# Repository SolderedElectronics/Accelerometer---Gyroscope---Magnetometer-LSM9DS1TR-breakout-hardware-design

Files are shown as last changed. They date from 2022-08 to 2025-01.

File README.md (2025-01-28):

# Accelerometer & Gyroscope & Magnetometer LSM9DS1TR 9-DOF breakout Hardware Design

## About the Product

| Accelerometer & Gyroscope & Magnetometer LSM9DS1TR 9-DOF breakout Image |
| :----------------------------------------------------------: |
| [Buy Accelerometer & Gyroscope & Magnetometer LSM9DS1TR 9-DOF breakout](https://www.solde.red/333069) |

Discover the magic of motion tracking with our all-in-one Accelerometer, Gyroscope & Magnetometer LSM9DS1TR Breakout! This mini but mighty module bundles together a 3D accelerometer, a 3D gyroscope, and a 3D magnetometer. It lets you monitor not only linear and rotational movements but also the magnetic field surrounding your projects. Despite its pocket-size, it offers high-accuracy measurements — ±16 g for the accelerometer, ±2000 dps for the gyroscope, and ±16 Gauss for the magnetometer.

It has an embedded temperature sensor, FIFO buffer for data management, and interrupt features to signal your microcontroller when data is ready or when a certain event occurs. Plus, with I2C interface, it can easily connect with a variety of microcontrollers.

Our LSM9DS1TR breakout merges high-end capabilities with a user-friendly approach. It operates within a supply voltage range of 2.4V to 3.6V, making it compatible with both 3.3V and 5V systems. Its low-power and power-down modes optimize performance without draining too much energy.

This breakout board comes with 2 easyC connectors which will simplify connection with microcontrollers. By using the easyC module connection system, forget about incorrectly connected or, in the worst case, damaged modules.

---

## Repository Contents

This repository contains all design files for Accelerometer & Gyroscope & Magnetometer LSM9DS1TR 9-DOF breakout, organized as follows:

- **`CAD` folder**: Contains KiCAD design files, including:
  - Schematics
  - PCB layout
  - Panel PCB layout
  - Source 3D files in Fusion360, if any
  - All files are sorted by version with a detailed change log.
- **`OUTPUTS` folder**: Includes all production-ready files, such as:
  - Bill of Materials (BOM) and interactive BOM (iBOM)
  - PDF versions of schematics
  - 3D `.step` file of the board
  - 3D-printable models
  - Gerber files for PCB manufacturing
  - Image of the pinout of the board
  - Product image
  - Compliance, legal and generic sales documents

Refer to the `Change Log` in the CAD folder for details about updates between versions.

---

## Learn More About the Product

Beyond the repository, explore the following resources:

### Soldered Verify

Soldered Verify Logo

The **Soldered Verify** system ensures every board you purchase from Soldered is fully functional. It also provides access to exclusive test data for your product. To get started, find the unique Soldered Verify ID on your product's packaging and enter the ID on the [Soldered Verify page](https://soldered.com/verify/) to access test results and additional product details.

### Soldered Community

soldered-verify-logo

Soldered Community is your go-to place for technical support. Our engineers track and answer all questions posted there, and it’s a great space for the maker community. Get answers to your questions and solutions for your challenges at [Soldered Community](https://soldered.com/community).

### solde.red

solde.red is an ultimate URL shortener and information hub. Access it by typing solde.red/ followed by your product SKU, e.g., [solde.red/333000](https://solde.red/333000), to find getting-started guides, datasheets, open-source hardware and software files, certifications, images, pinouts, and more. Read more about the shortener [here](https://solde.red/info/).

---

## Contributing

Contributions are welcome! Here’s how you can get involved:

- Submit pull requests to enhance the design or fix issues.
- Report bugs or problems by opening an issue.

We encourage community collaboration to make this product even better.

---

## About Soldered

soldered-logo

[Soldered for Makers](https://soldered.com) specializes in designing and manufacturing electronic products tailored for enthusiasts, ranging from hobbyists to professionals. Our portfolio includes electronic boards, sensors, and actuators that are widely utilized in fields such as microelectronics, mechatronics, robotics, programming, and IoT. Every product we offer is designed in-house and built upon open-source hardware and software platforms. Proudly certified and manufactured within the European Union, our catalog likely includes the product you need for your project.

We complement these products with comprehensive tutorials and manuals, product descriptions, schematics, programming codes, and project examples. Our round-the-clock [customer and technical support](https://soldered.com/community) is available for all our products, irrespective of the sales channel. Soldered’s success and services reflect our maker community’s unwavering [trust](https://www.trustpilot.com/review/soldered.com), for which we are deeply grateful. Join our community and create using Soldered products.

---

## License

All Soldered open-source hardware (OSH) is under The TAPR Open Hardware License. Read more in the LICENSE file located in this repository.

**Disclaimer:**

No warranty - all designs in this repository are distributed in the hope that they will be useful, but without any warranty. They are provided "AS IS", therefore without warranty of any kind, either expressed or implied. The entire quality and performance of what you do with the contents of this repository are your responsibility. In no event Soldered Electronics will be liable for your damages, or losses, including any general, special, incidental, or consequential damage arising out of the use or inability to use the contents of this repository. 

---

## Have fun!

Thank you for your support from your fellow makers at Soldered Electronics.

Happy Making!

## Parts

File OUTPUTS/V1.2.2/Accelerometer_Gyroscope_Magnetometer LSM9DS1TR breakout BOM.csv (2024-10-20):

Id | Designator | Package | Quantity | Designation | Supplier and ref
1 | R6,R4,R8,R2,R1,R7,R5,R3 | 0603R | 8 | 10k
2 | C6,C7 | 0603C | 2 | 2u2
3 | K2,K4 | easyC-connector | 2 | easyC-SMD
4 | JP6 | SMD-JUMPER-CONNECTED_TRACE_SLODERMASK | 1 | SMD-JUMPER-CONNECTED_TRACE_SLODERMASK
5 | C3 | 1206C | 1 | 10u
6 | C5,C2,C1 | 0603C | 3 | 100n
7 | REF** | Symbol-Front-Orientation2 | 1 | Symbol-Front-Orientation2
8 | JP5,JP1,JP2,JP3 | SMD_JUMPER_3_PAD_TRACE | 4 | SMD_JUMPER_3_PAD_TRACE
9 | U1 | SOT-363 | 1 | NMOS-DUAL
10 | C4 | 0603C | 1 | 10n
11 | U3 | SOT-23-5 | 1 | SE5218
12 | U2 | LSM9DS1TR | 1 | LSM9DS1TR
13 | H1,H2 | HOLE_3.2mm | 2 | HOLE_3.2mm
14 | JP4 | SMD_JUMPER | 1 | SMD_JUMPER
15 | K3 | HEADER_MALE_4X1 | 1 | HEADER_MALE_4X1
16 | K1 | HEADER_MALE_9X1 | 1 | HEADER_MALE_9X1

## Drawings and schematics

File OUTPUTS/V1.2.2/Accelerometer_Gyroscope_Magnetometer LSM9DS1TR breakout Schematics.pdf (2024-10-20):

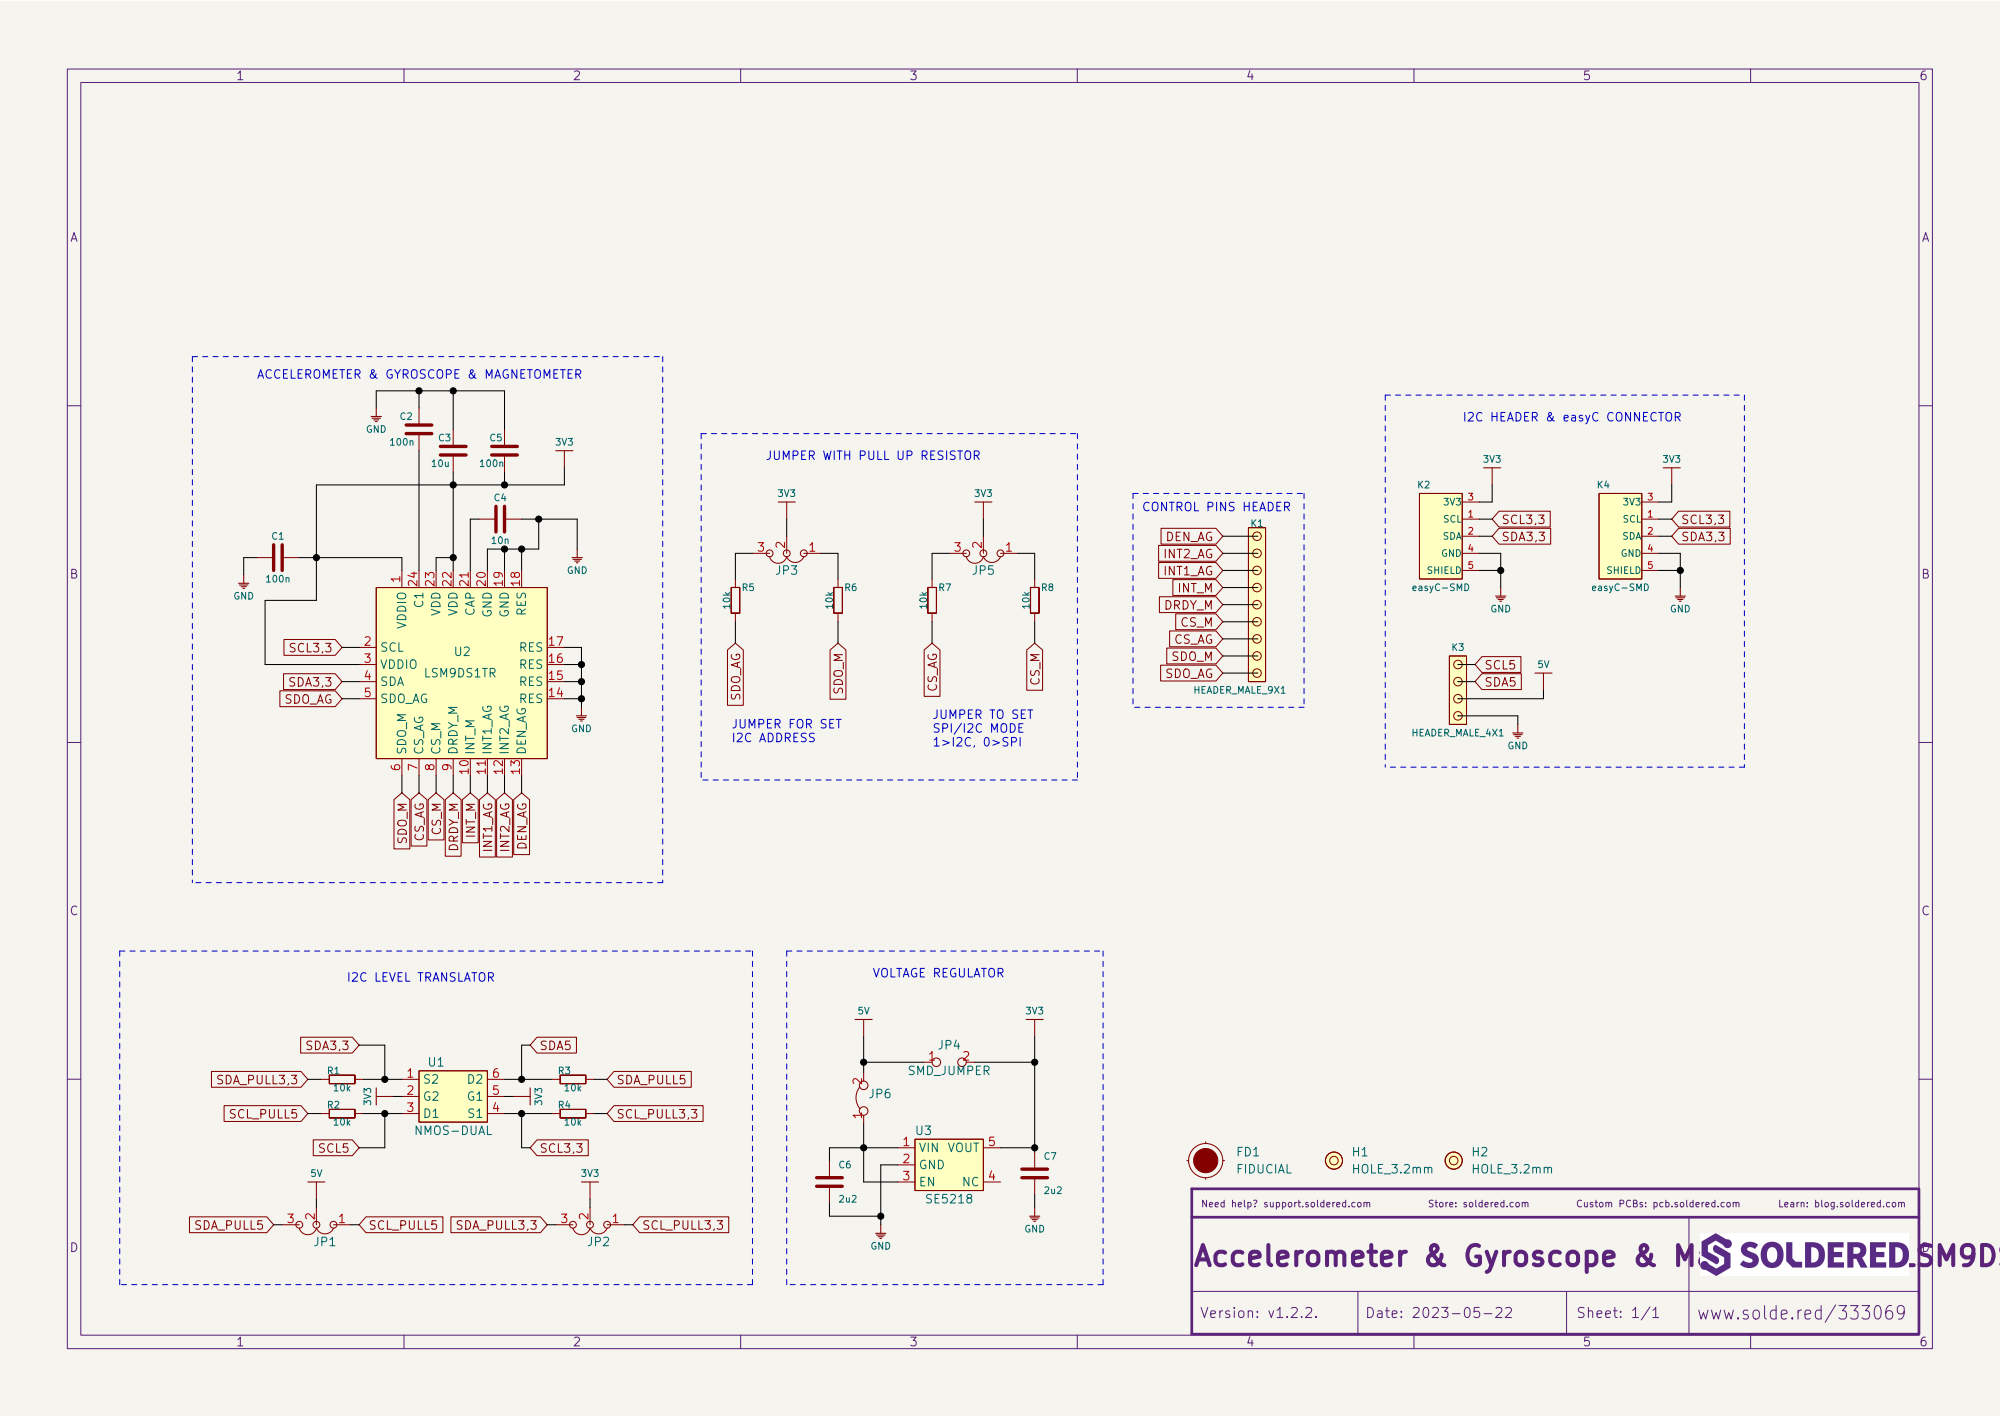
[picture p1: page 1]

JUMPER WITH PULL UP RESISTOR

1 INT_M 10 INT1_AG 11 INT2_AG 12 DEN_AG 13 RES 14 RES 15 RES 16 RES 17 RES 18 GND 19 SCL 2 GND 20 CAP 21 VDD 22 VDD 23 C1 24 VDDIO 3 SDA 4 SDO_AG 5 SDO_M

JUMPER TO SET SPI/I2C MODE

Learn: blog.soldered.com

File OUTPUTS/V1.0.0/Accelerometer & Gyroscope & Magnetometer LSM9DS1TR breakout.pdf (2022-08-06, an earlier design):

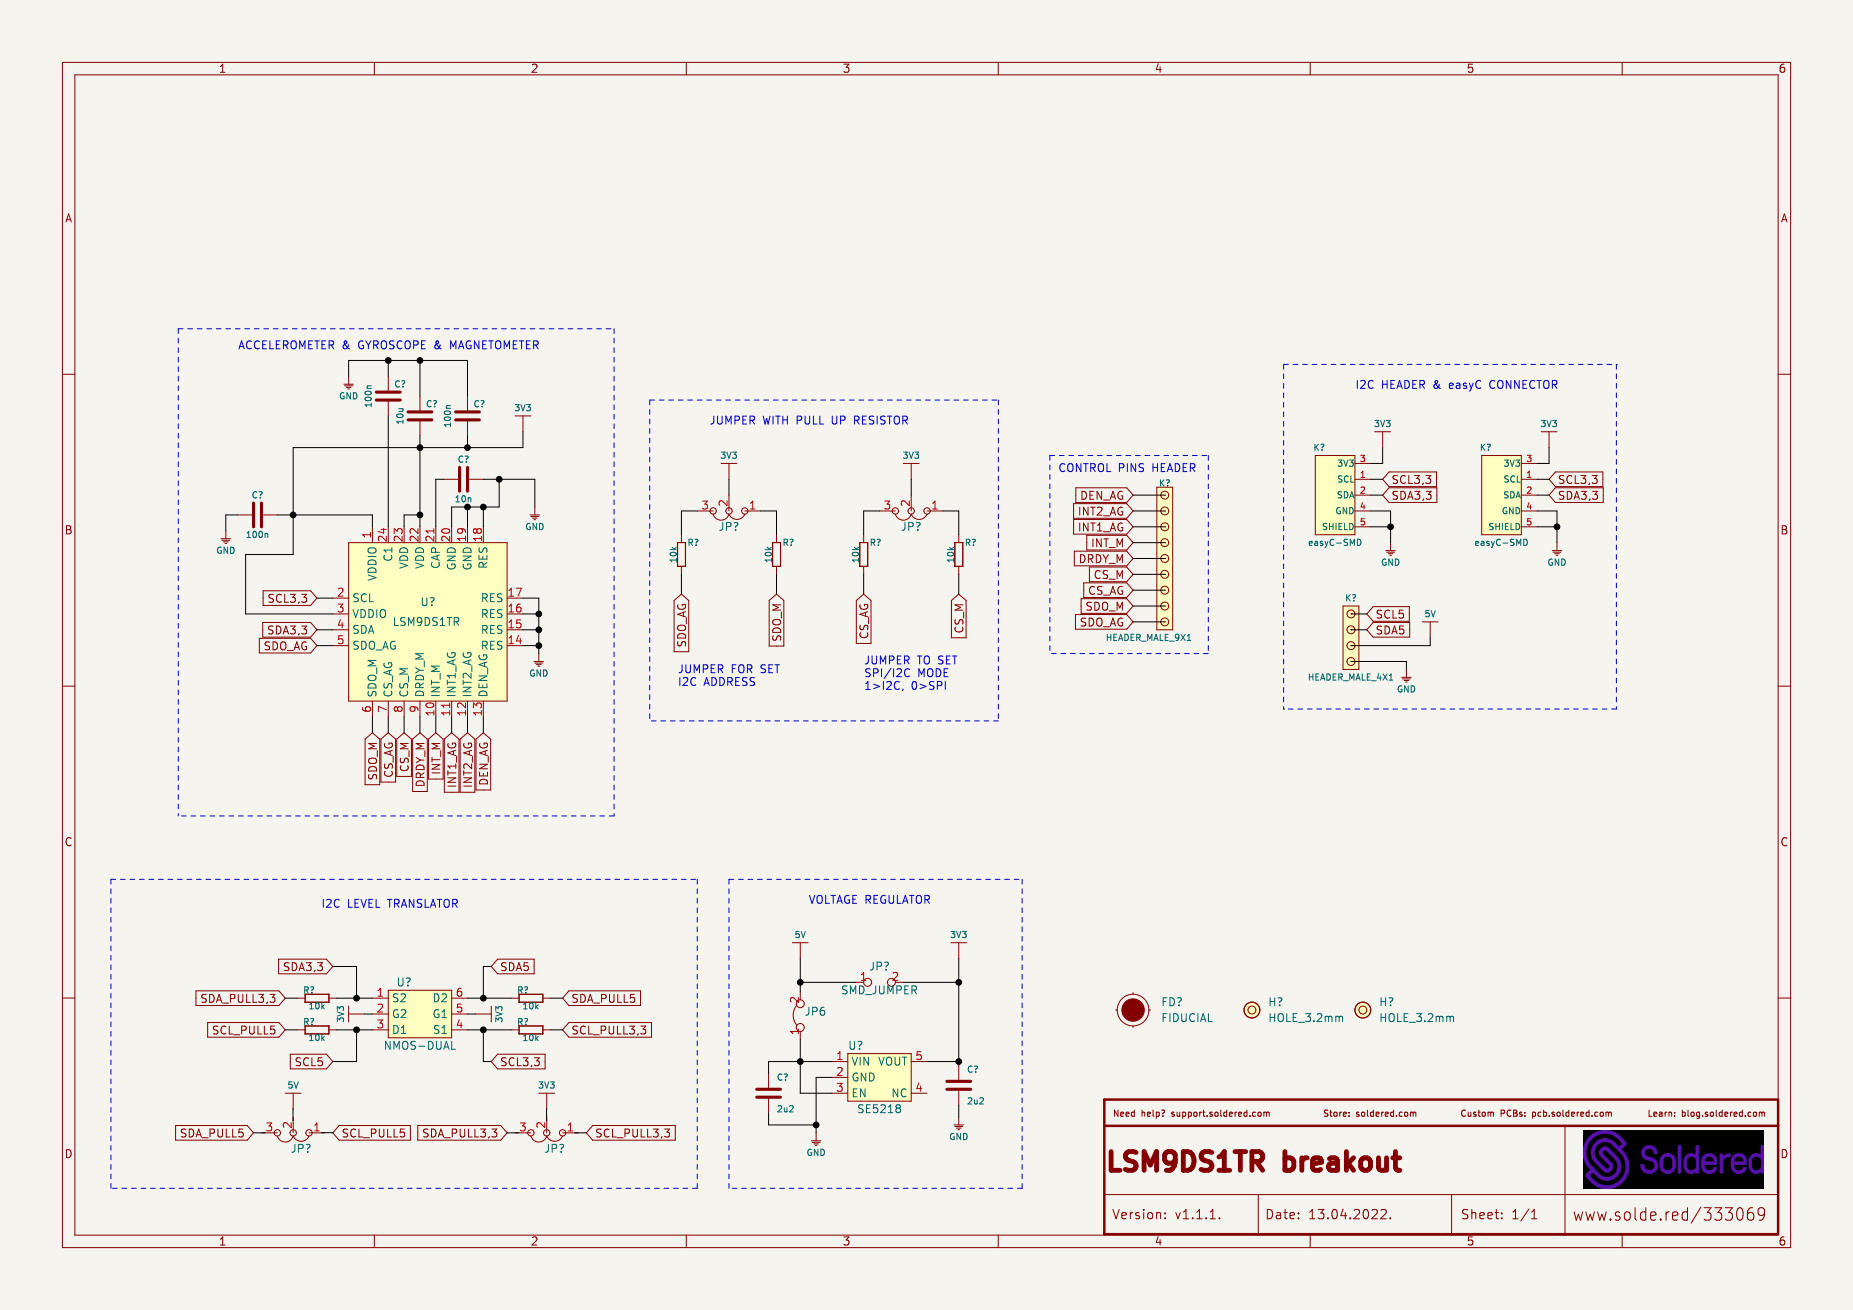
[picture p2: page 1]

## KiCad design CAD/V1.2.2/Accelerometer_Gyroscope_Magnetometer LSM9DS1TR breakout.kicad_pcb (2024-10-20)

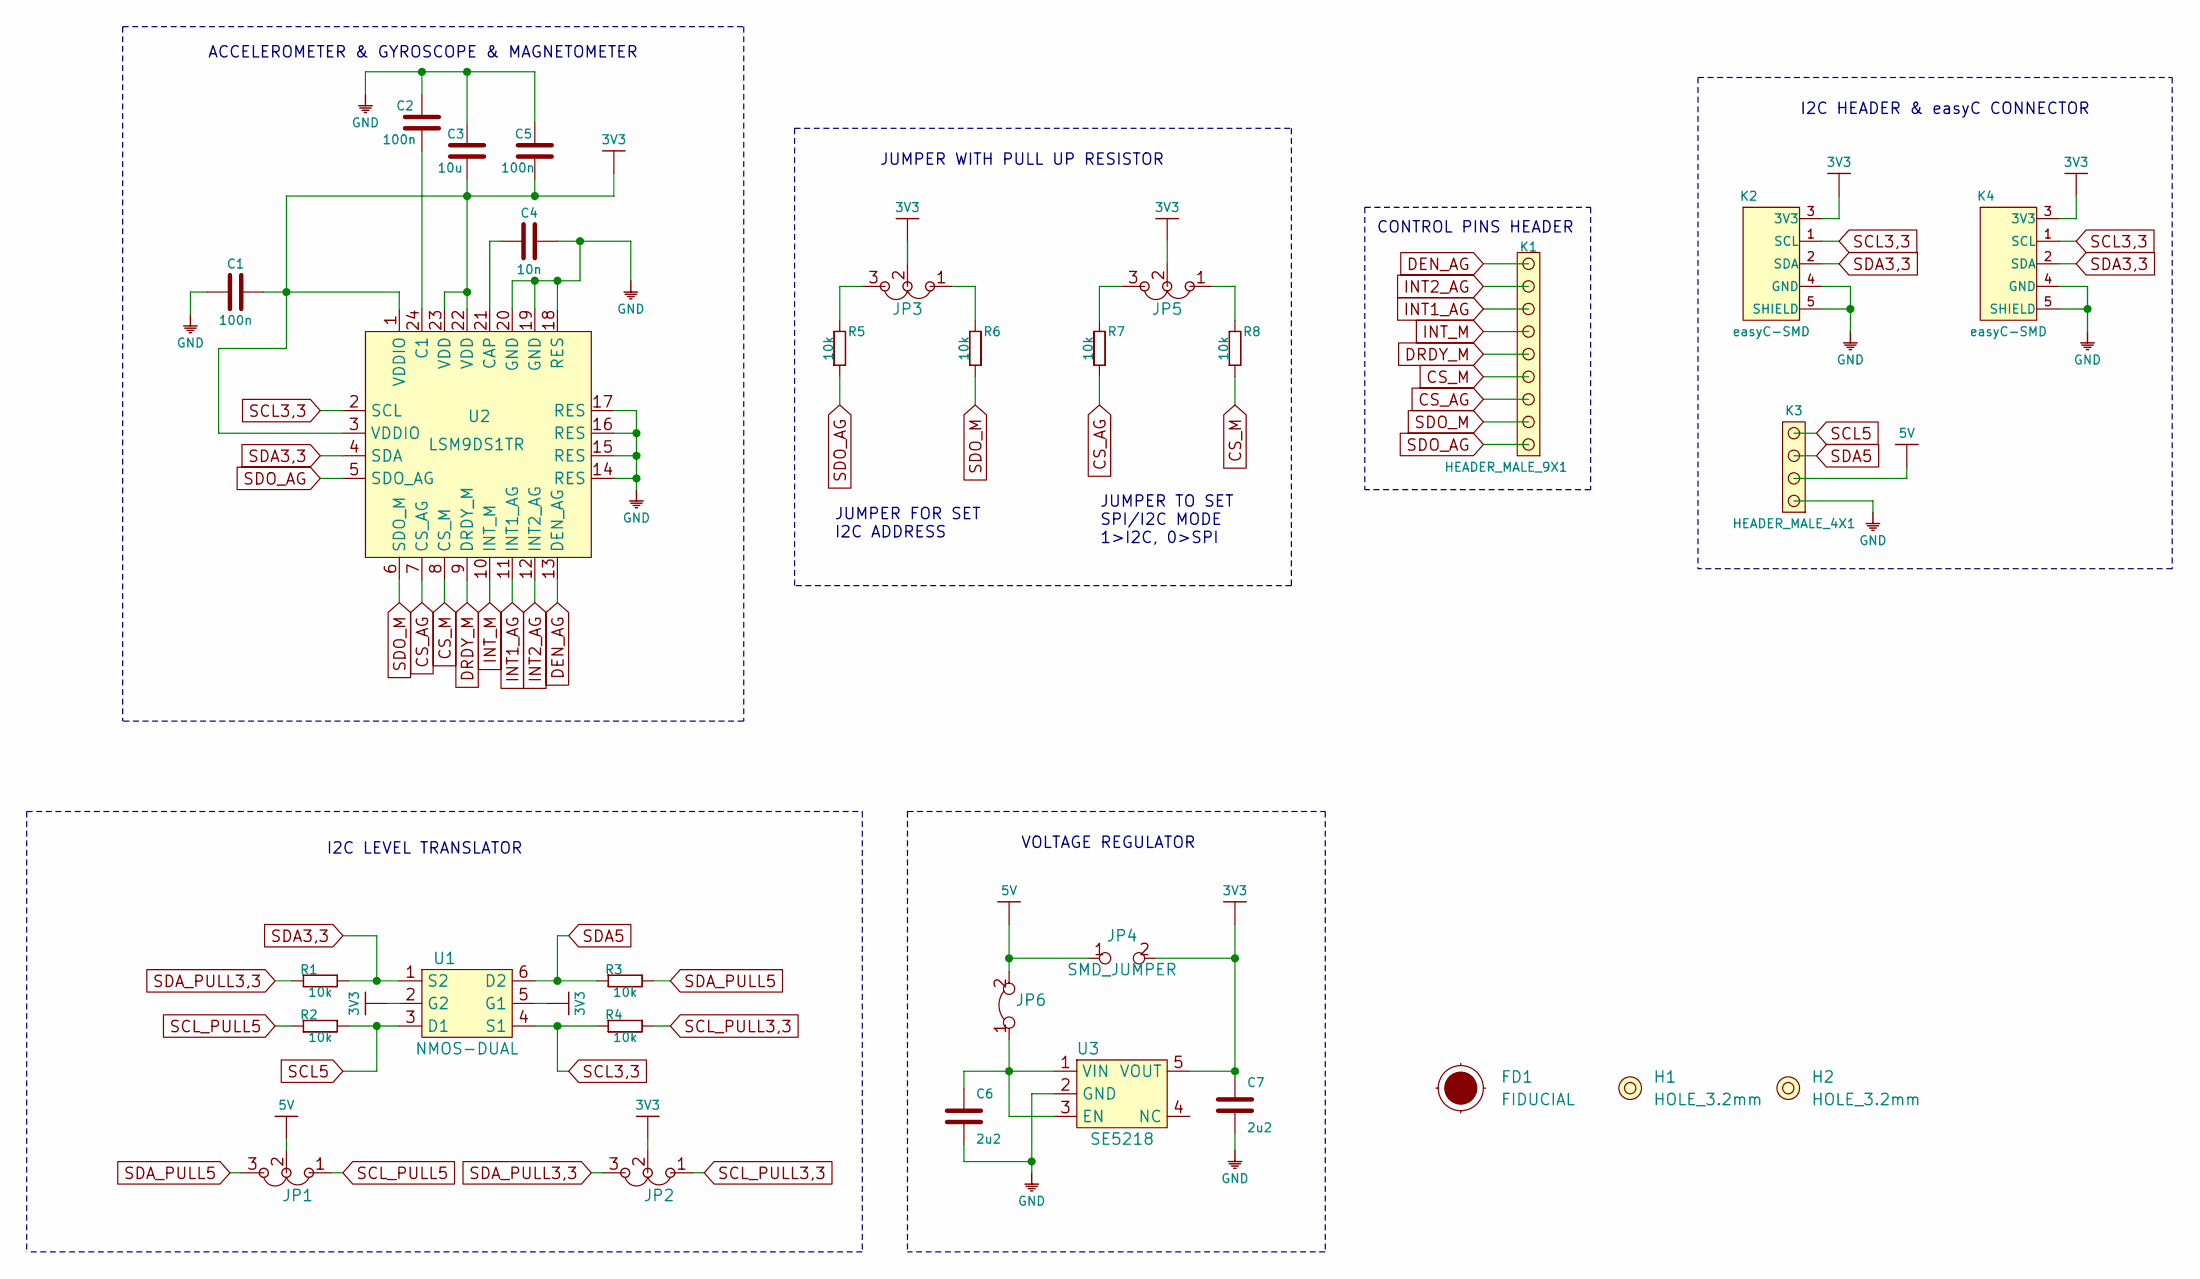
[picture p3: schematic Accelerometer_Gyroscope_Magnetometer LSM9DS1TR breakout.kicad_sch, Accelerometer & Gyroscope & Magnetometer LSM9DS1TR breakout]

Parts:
C1, C2, C5: 100n; 0603C
C3: 10u; 1206C
C4: 10n; 0603C
C6, C7: 2u2; 0603C
FD1: FIDUCIAL; FIDUCIAL_23
H1, H2: HOLE_3.2mm
JP1, JP2, JP3, JP5: SMD_JUMPER_3_PAD_TRACE
JP4: SMD_JUMPER
JP6: SMD-JUMPER-CONNECTED_TRACE_SLODERMASK
K1: HEADER_MALE_9X1
K2, K4: easyC-SMD; easyC-connector
K3: HEADER_MALE_4X1
R1, R2, R3, R4, R5, R6, R7, R8: 10k; 0603R
U1: NMOS-DUAL; SOT-363
U2: LSM9DS1TR
U3: SE5218; SOT-23-5

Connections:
3V3: C1.2, C3.1, C5.2, C7.2, JP2.2, JP3.2, JP4.2, JP5.2, K2.3 (3V3), K4.3 (3V3), U1.2 (G2), U1.5 (G1), U2.1 (VDDIO), U2.3 (VDDIO), U2.22 (VDD), U2.23 (VDD), U3.5 (VOUT)
5V: JP1.2, JP4.1, JP6.2, K3.2
CS_AG: K1.3, R7.1, U2.7 (CS_AG)
CS_M: K1.4, R8.1, U2.8 (CS_M)
DEN_AG: K1.9, U2.13 (DEN_AG)
DRDY_M: K1.5, U2.9 (DRDY_M)
GND: C1.1, C2.2, C3.2, C4.2, C5.1, C6.1, C7.1, K2.4 (GND), K2.5 (SHIELD), K3.1, K4.4 (GND), K4.5 (SHIELD), U2.14 (RES), U2.15 (RES), U2.16 (RES), U2.17 (RES), U2.18 (RES), U2.19 (GND), U2.20 (GND), U3.2 (GND)
INT1_AG: K1.7, U2.11 (INT1_AG)
INT2_AG: K1.8, U2.12 (INT2_AG)
INT_M: K1.6, U2.10 (INT_M)
unnamed: C2.1, U2.24 (C1)
unnamed: C4.1, U2.21 (CAP)
unnamed: C6.2, JP6.1, U3.1 (VIN), U3.3 (EN)
unnamed: JP3.1, R6.2
unnamed: JP3.3, R5.2
unnamed: JP5.1, R8.2
unnamed: JP5.3, R7.2
SCL3,3: K2.1 (SCL), K4.1 (SCL), R4.1, U1.4 (S1), U2.2 (SCL)
SCL5: K3.4, R2.2, U1.3 (D1)
SCL_PULL3,3: JP2.1, R4.2
SCL_PULL5: JP1.1, R2.1
SDA3,3: K2.2 (SDA), K4.2 (SDA), R1.2, U1.1 (S2), U2.4 (SDA)
SDA5: K3.3, R3.1, U1.6 (D2)
SDA_PULL3,3: JP2.3, R1.1
SDA_PULL5: JP1.3, R3.2
SDO_AG: K1.1, R5.1, U2.5 (SDO_AG)
SDO_M: K1.2, R6.1, U2.6 (SDO_M)

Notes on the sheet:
CONTROL PINS HEADER
JUMPER WITH PULL UP RESISTOR
ACCELEROMETER & GYROSCOPE & MAGNETOMETER
VOLTAGE REGULATOR
JUMPER FOR SET I2C ADDRESS
JUMPER TO SET SPI/I2C MODE 1>I2C, 0>SPI
I2C HEADER & easyC CONNECTOR
I2C LEVEL TRANSLATOR

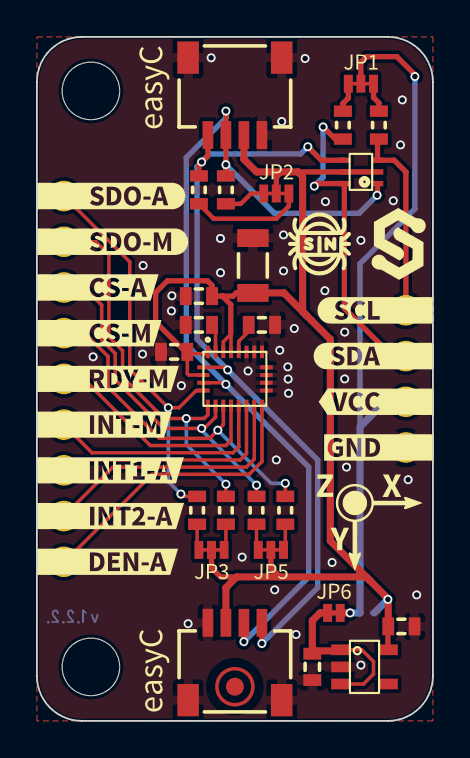
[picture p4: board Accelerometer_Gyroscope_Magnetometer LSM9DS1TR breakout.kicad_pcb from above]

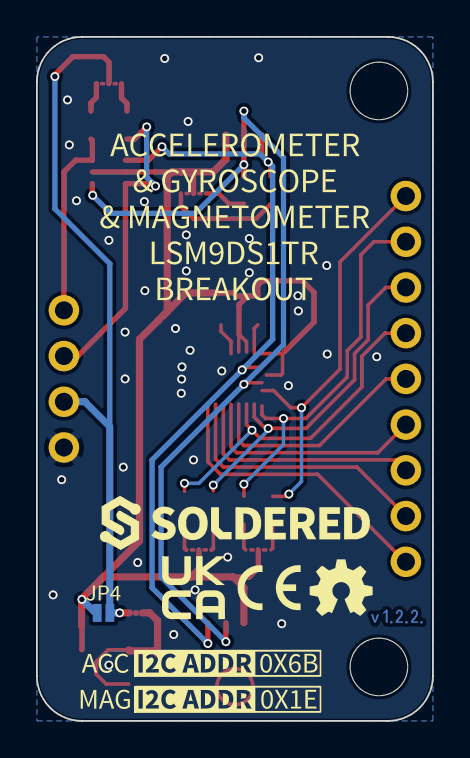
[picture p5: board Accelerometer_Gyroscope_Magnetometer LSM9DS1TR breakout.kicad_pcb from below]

Board: 2 copper layers, 22.0 x 38.0 mm, 59 parts (13 on the bottom side), 27 nets.

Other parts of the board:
kibuzzard-646B23F4: G***; kibuzzard-646B23F4
kibuzzard-6411B0B5: G***; kibuzzard-6411B0B5
kibuzzard-6411B0E0: G***; kibuzzard-6411B0E0
kibuzzard-6411B0F4: G***; kibuzzard-6411B0F4
kibuzzard-6411B1B6: G***; kibuzzard-6411B1B6
kibuzzard-6411B1E2: G***; kibuzzard-6411B1E2
kibuzzard-6411B1FF: G***; kibuzzard-6411B1FF
kibuzzard-6411B2B7: G***; kibuzzard-6411B2B7
kibuzzard-6411B2D2: G***; kibuzzard-6411B2D2
kibuzzard-6411B06B: G***; kibuzzard-6411B06B
kibuzzard-6411B07F: G***; kibuzzard-6411B07F
kibuzzard-6411B21F: G***; kibuzzard-6411B21F
kibuzzard-6411B22F: G***; kibuzzard-6411B22F
kibuzzard-6411B25F: G***; kibuzzard-6411B25F
kibuzzard-6411B32F: G***; kibuzzard-6411B32F
kibuzzard-6411B33C: G***; kibuzzard-6411B33C
kibuzzard-6411B059: G***; kibuzzard-6411B059
kibuzzard-6411B061: G***; kibuzzard-6411B061
kibuzzard-6411B074: G***; kibuzzard-6411B074
kibuzzard-6411B103: G***; kibuzzard-6411B103
kibuzzard-6411B119: G***; kibuzzard-6411B119
kibuzzard-6411B182: G***; kibuzzard-6411B182
kibuzzard-6411B196: G***; kibuzzard-6411B196
kibuzzard-6411B241: G***; kibuzzard-6411B241
kibuzzard-6411B292: G***; kibuzzard-6411B292
kibuzzard-6411B295: G***; kibuzzard-6411B295
kibuzzard-6411B327: G***; kibuzzard-6411B327
kibuzzard-6411B347: G***; kibuzzard-6411B347

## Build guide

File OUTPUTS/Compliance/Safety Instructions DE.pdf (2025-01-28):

BITTE BEWAHREN SIE DIESE INFORMATIONEN ZUR SPÄTEREN VERWENDUNG AUF.
LESEN SIE VOR DER VERWENDUNG DIESES PRODUKTS ALLE ANWEISUNGEN IN DOKUMENT. Produktname: Accelerometer & Gyroscope & Magnetometer LSM9DS1TR breakout
Die ersten Schritte:Besuchen Sie www.soldered.com, um loszulegen.

## WARNUNGEN

- Dieses Produkt sollte nicht abgedeckt werden und in einer gut belüfteten Umgebung betrieben werden.
- Das Produkt sollte auf einer stabilen, flachen, nicht leitenden Oberfläche aufgestellt werden und nicht mit leitenden Gegenständen in Berührung kommen.
- Der Anschluss anderer Geräte kann die Konformität beeinträchtigen oder zu Schäden am Gerät führen und zum Erlöschen der Garantie führen.
- Wenn Peripheriegeräte angeschlossen werden, die nicht das Kabel oder den Stecker enthalten, muss das verwendete Kabel oder muss das verwendete Kabel bzw. der verwendete Steckverbinder eine angemessene Isolierung und Funktion aufweisen, damit die Anforderungen die einschlägigen Leistungs- und Sicherheitsanforderungen erfüllt werden.
- Es besteht Explosionsgefahr, wenn die Batterie falsch eingesetzt wird.
- Das Produkt sollte nicht außerhalb des angegebenen Arbeitsbereichs verwendet werden.

## HINWEISE ZUR SICHEREN ANWENDUNG

Um Fehlfunktionen oder Schäden an Ihrem Gerät zu vermeiden, beachten Sie bitte die folgenden Hinweise:
- Setzen Sie das Gerät nicht Wasser oder Feuchtigkeit aus und stellen Sie es nicht auf eine
leitende Oberfläche, wenn es eingeschaltet ist. Das Gerät nicht mit nassen Händen anfassen.
- Setzen Sie es keiner Wärmequelle aus; das Produkt ist für die Verwendung bei normalen Raumtemperaturen ausgelegt. Das Produkt ist für die Verwendung in Innenräumen vorgesehen.
- Seien Sie bei der Handhabung vorsichtig, um mechanische oder elektrische Schäden an Teilen des Geräts zu vermeiden. Fassen Sie das Gerät nicht an, wenn es unter Spannung steht. Verwenden Sie einen ESD-Schutz.
- Verwenden Sie nur das mitgelieferte Kabel (oder ein gleich- oder höherwertiges Kabel)
mit dem Gerät.

## COMPLIANCE-INFORMATIONEN

Das Produkt entspricht den entsprechenden Bestimmungen der RoHS-Richtlinie für die Europäische Union. Wie alle elektrischen und elektronischen Geräte (EEE), sollte das Produkt nicht über den Hausmüll entsorgt werden.
ELEKTROMAGNETISCHE VERTRÄGLICHKEIT UND BETRIEB
- Das Produkt entspricht den Schutzanforderungen der Richtlinie des EU-Rates 2014/30/EU über die Rechtsvorschriften der Mitgliedstaaten zur elektromagnetischen Verträglichkeit und den Elektromagnetische Verträglichkeitsverordnung 2016 des Vereinigten Königreichs.
- WARNUNG: Bitte verändern Sie nicht das Design dieses Produkts, da dies dazu führen kann, dass Sie das Produkt nicht mehr uneingeschränkt nutzen können.
Dies gilt auch für die Änderung der Frequenz, mit der das Produkt arbeitet.

## Einhaltung gesetzlicher Vorschriften und wichtige

Soldered Electronics d.o.o., Vinkovačka cesta 68, 31000 Osijek, Croatia. VAT ID: HR83200237288

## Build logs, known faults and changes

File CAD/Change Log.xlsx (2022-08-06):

CHANGE LOG
 | Latest version |  |  | v1.0.0.
 |  | Product name: |  | Accelerometer & gyroscope & magnetometer LSM9DS1TR
 |  | Release date: |  | 16.8.2021.
 |  | Release author: |  | Ivan Fadiga
Version: | v1.0.0. | Author: | Ivan Fadiga | Date: | 16.8.2021.
List of Changes
 | Initial document
Version: | v1.1.1. | Author: | Ivan Hotovec | Date: | 14.4.2022.
List of Changes
 | Changed pad size on footprint for LSM9DS1
Version: |  | Author: |  | Date:
List of Changes
